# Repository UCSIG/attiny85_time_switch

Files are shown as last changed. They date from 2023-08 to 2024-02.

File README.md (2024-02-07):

# ATtiny85 Time Switch

## Low-power 12/24V time switch with undervoltage protection using the internal oscillator of the ATtiny85

The aim of this project is to switch a load on and off in regular time intervals. The device itself consumes only very little sleep current (~19.6uA on average).  
The device also monitors the supply voltage and turns off the load if the supply drops lower than the defined threshold.

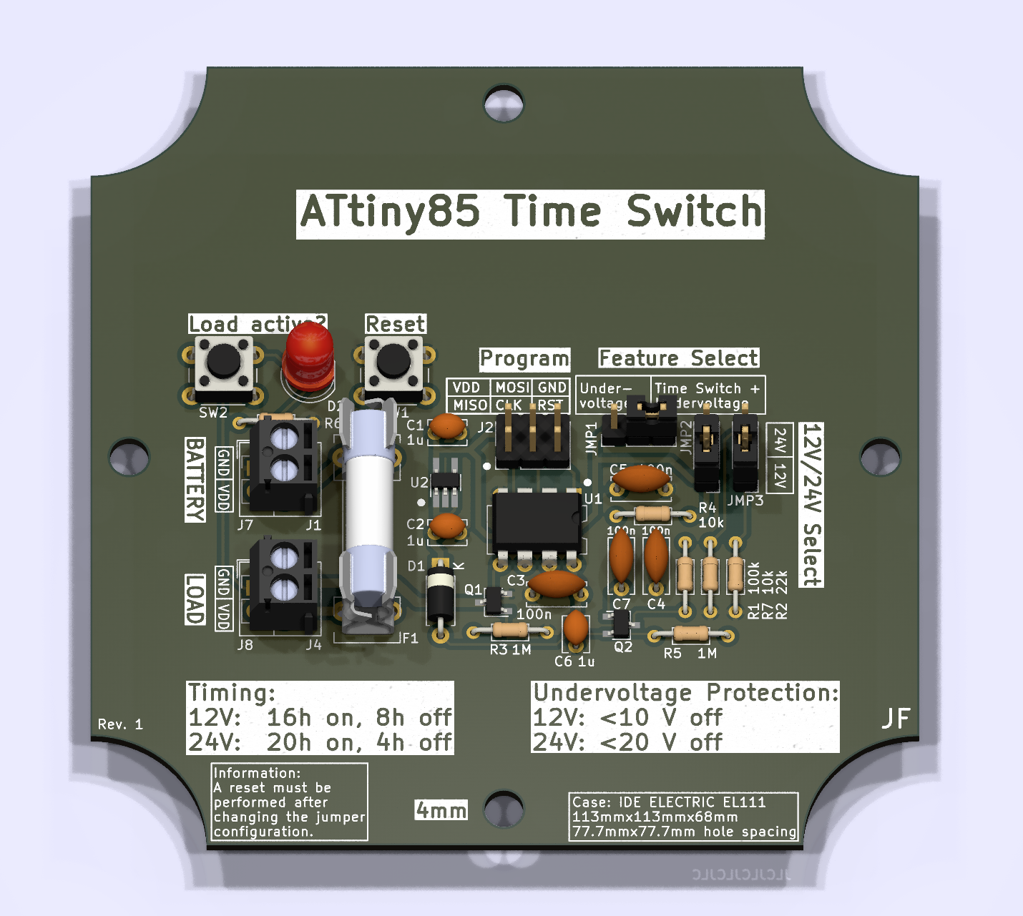
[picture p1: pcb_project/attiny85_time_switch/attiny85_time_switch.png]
PCB 3D View


## Features

- Clock calibration algorithm with values stored in the internal eeprom
- Supply voltage monitoring
- Jumper configuration for feature selection (supply voltage monitoring + time switch/only supply voltage monitoring)
- Jumper configuration for undervoltage threshold selection (12/24V)
- Low current consumption (~19.6uA)

## Specifications

| Type | Value |
| --- | --- |
| Average Current Consumption | 19.6uA |
| Maximum Load Current | 5.7A (cont.) |
| Supply Voltages | 12/24V |
| Switch Type | Low-Side |

## Detailed Description

There are three jumpers which must be set to either select the 12V or the 24V configuration. This changes the on/off times as well as the undervoltage thresholds.  
Every time the jumper configuration is changed, a reset must be performed for the changes to take effect.  

Upon coming out of reset, the device reads its clock calibration values stored in the internal eeprom to provide accurate timings for the time switch.

The device wakes up periodically and immediately goes back to sleep. That way, very long deep sleep periods can be reached.  
The ATtiny85 runs off of the internal 128kHz low speed oscillator during deep sleep. The watchdog timer wakes up the device every 8.192s (the maximum watchdog timeout) and the ATtiny increments a counter variable.
If it surpasses a pre-defined threshold, the load switch changes state from on->off or the other way round.  

Every 15 minutes it also measures the supply voltage and compares it to a pre-defined threshold. If the supply is lower than that threshold, the load is switched off until the device is reset.  
The maximum load current is determined by the sizing of the n-fet Q1. With the n-fet PMV20XNER one can switch up to 5/7A. The load is switched with a low side switch.  

The internal 8MHz oscillator of the ATtiny85 is used as the primary clock source. However, the clock frequency can vary by up to ±15%. In order to get accurate on/off times from the time switch,
this internal oscillator must be calibrated. A detailed description of how to do that can be found [here](clock_calibrations/clock_calibrations.md).

## Mechanical

The pcb is designed to fit in the [EL111](https://ide.es/eng/products/junction-boxes-and-mechanisms/ip65-ip67-junction-boxes/ref_EL111) enclosure by IDE electric.
It is screwed into the case using four M4 screws. The case itself is rated IP65-67. Its dimensions are 113x113x68 mm (Height x Width x Depth).

## Project structure

The code resides in the folder `src` and `include`. PlatformIO is chosen as the build environment. The best way to program the ATtiny85 is to use PlatformIO and VS Code as the IDE.  
The pcb project can be found under `pcb_project/attiny85_time_switch`. The relevant code snippets for changing the timing values and the undervoltage thresholds are at the top of `main.cpp`.
The gerber files are in `pcb_project/attiny85_time_switch/fabrication_outputs/`.

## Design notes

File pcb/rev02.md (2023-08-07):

# ATtiny85 Time Switch Future Revisions

## Rev02

- Use bigger screw terminals (currently 3.5mm hole distance, thats too small, use something like 5mm)

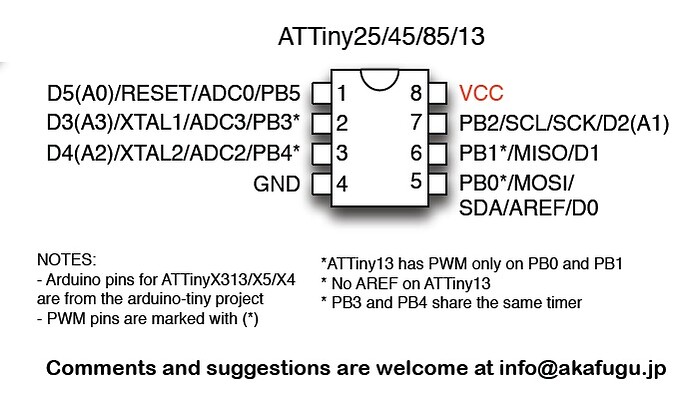
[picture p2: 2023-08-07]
docu/ATtiny85_pinout.jpeg

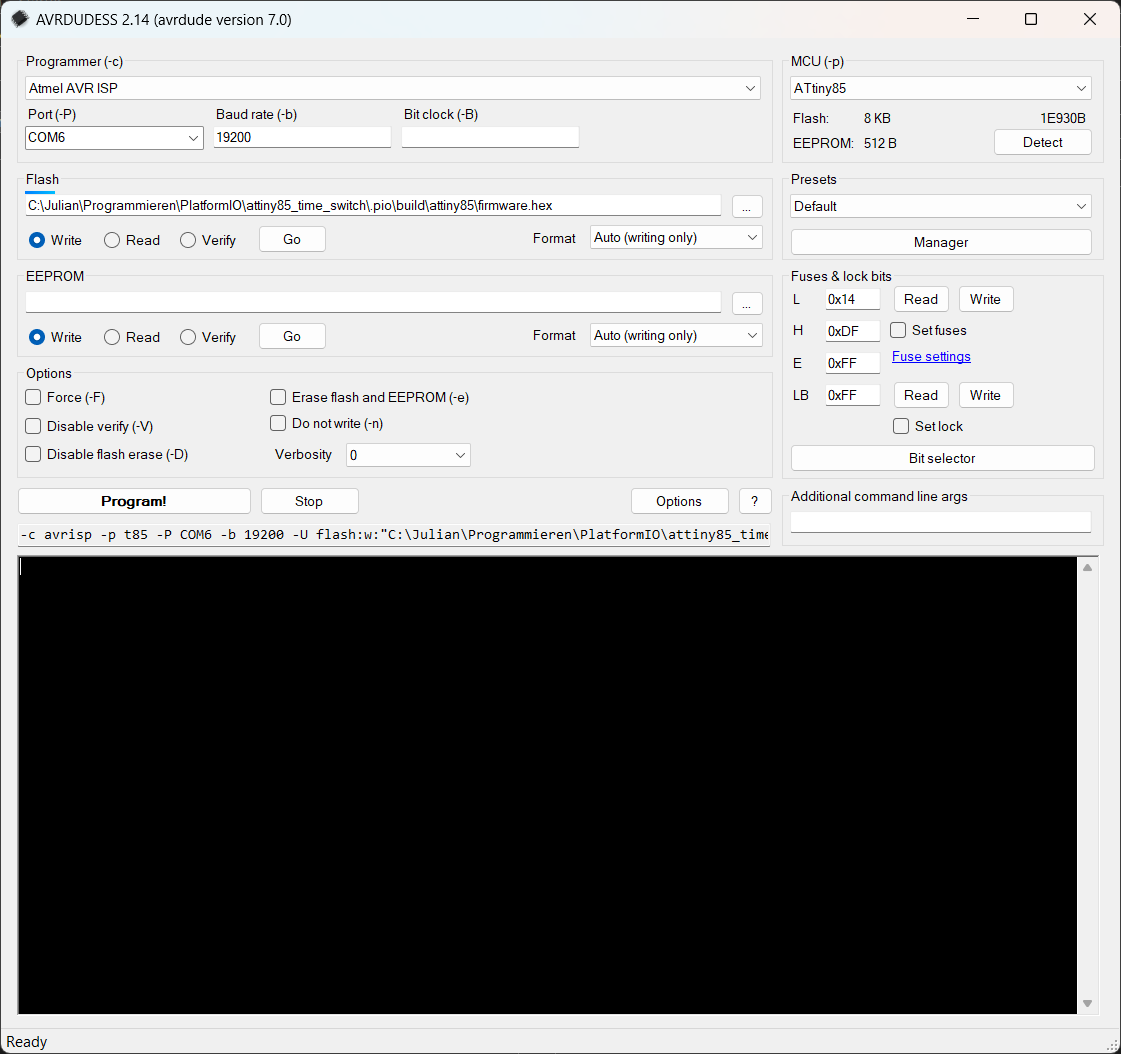
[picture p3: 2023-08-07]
docu/avr_dudess_settings.png

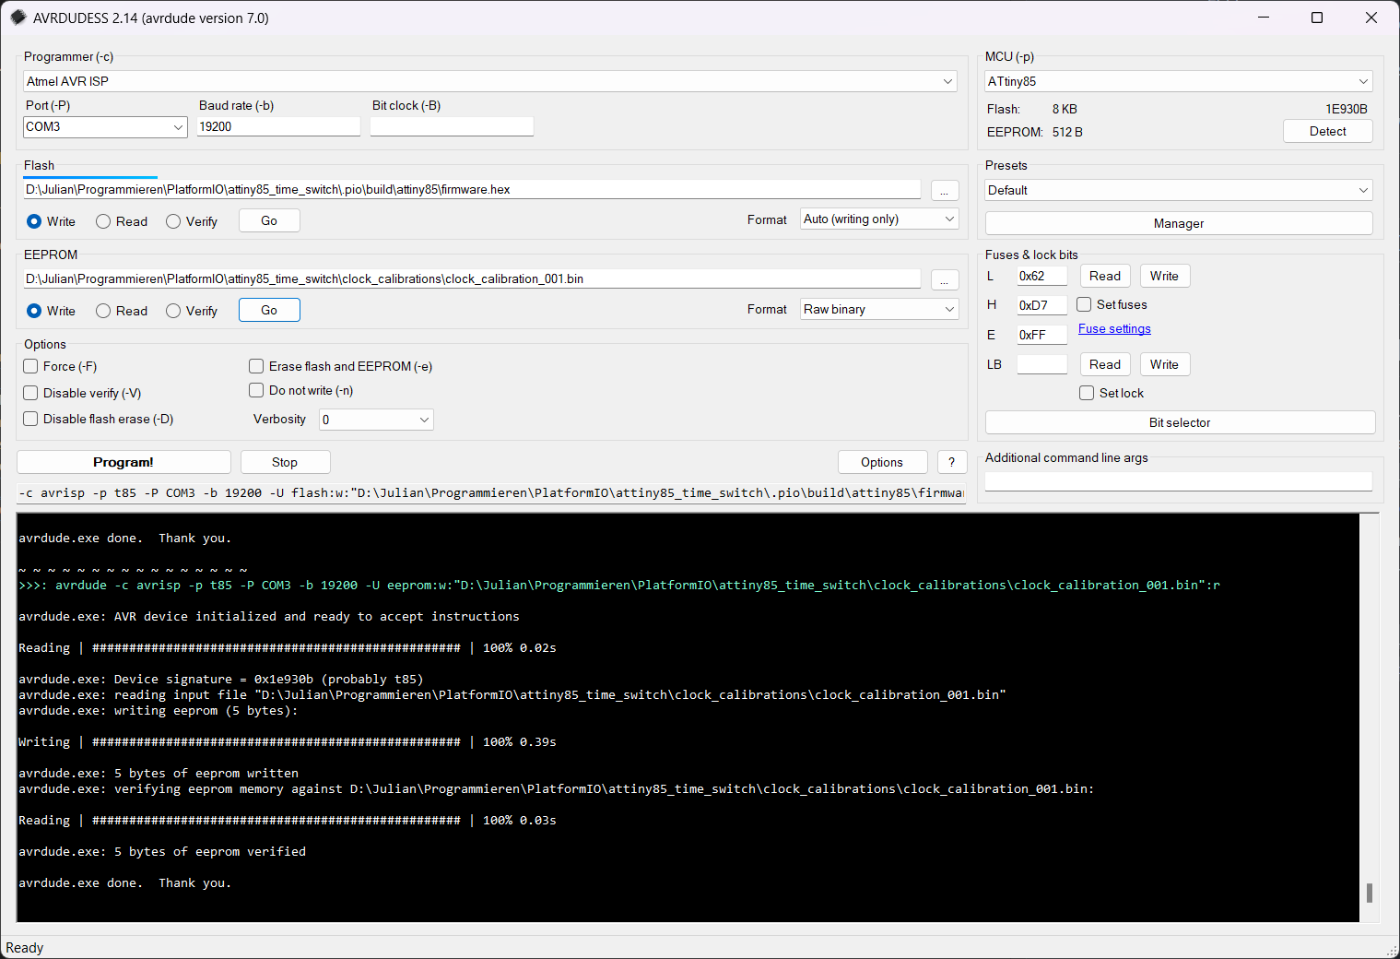
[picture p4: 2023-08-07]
docu/avr_dudess_eeprom_settings.png

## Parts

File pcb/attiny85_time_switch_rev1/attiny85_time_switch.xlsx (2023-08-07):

Reference | Value | Link | Manufacturer Part Number | Menge | So viel haben wir schon
C1, C2, C6 | 1u | https://de.farnell.com/tdk/fg18x5r1h105krt06/kondensator-1uf-50v-mlcc-radial/dp/3619045 | FG18X5R1H105KRT06 | 3 | 38
C3-C5, C7 | 100n | https://de.farnell.com/suntan/ts170r1h104msbfb0r/kondensator-0-1-f-50v-20-y5v/dp/2901306?ost=2901306 | TS170R1H104MSBFB0R | 4 | 35
Case1 | EL111 | https://ide.es/deu/produkte/abzweigdosen-und-schalterdosen/ip65-ip67-ap-abzweigdosen-und-motorschutzgehause/ref_EL111 | EL111 | 1 | Hast du schon glaub ich
D1 | D | https://de.farnell.com/on-semiconductor/1n4007rlg/diode-std-erholzeit-1a-1kv-axial/dp/2317678?st=1n4007 | 1N4007RLG | 1 | Musst du schauen, ob du neue Verpolschutzdioden willst oder einfach irgendeine nimmst die rumliegt
D2 | LED | https://de.farnell.com/multicomp/703-0100/led-rot-5mm-standard/dp/2112111?st=led%205mm | 703-0100 | 1 | Halt eine LED :D
F1 | 0751.0052 | https://de.farnell.com/schurter/0751-0052/fuse-clip-pcb-mount/dp/2309093?ost=0751.0052 | 0751.0052 | 1 | Du meintest, du hast schon die Halterung und die Sicherung
J1, J4 | Screw_Terminal_01x02 | https://de.farnell.com/camdenboss/ctb0305-2/anschlussblock-2polig/dp/3882639?st=ctb0305 | CTB0305/2 | 2 | Je nachdem, wie du die Kabel befestigen willst, das wäre eine passende Schraubklemme mit 3.5mm Lochabstand
J2 | Conn_02x03_Pin | https://de.farnell.com/multicomp/2213s-06g/stecker-2-reih-vert-6kont/dp/1593440 | 2213S-06G | 1 | Vielleicht macht es Sinn, hier passende zweireihige Stiftleisten zu bestellen. Das ist für den Programmieranschluss, man könnte auch zwei einreihige Stiftleisten auf je 3 Kontakte schneiden und nebeneinander einlöten, aber ist doch cooler wenn das direkt gut passt alles
J3, J5, J6 | Conn_01x03_Pin | https://de.farnell.com/multicomp/spc20484/stecker-1reihen-40kont/dp/1462888 | SPC20484 | 3 | Standard 2.54mm Stiftleisten, die für die Jumperkonfiguration gebraucht wird. Wir brauchen pro Platine 9 Kontakte für die Jumperkonfiguration, und 4 Kontakte falls du da die Kabel für Batterie und Last anschließen willst (anstelle von anlöten oder Schraubklemmen)
J7, J8 | Conn_01x02_Pin | https://de.farnell.com/multicomp/spc20484/stecker-1reihen-40kont/dp/1462888 | SPC20484 | 2 | wie oben
Q1 | PMV20XNER | https://de.farnell.com/nexperia/pmv20xner/mosfet-n-kanal-30v-5-7a-to236ab/dp/2498579?ost=2498579 | PMV20XNER | 1 | 0
Q2 | PMV65XP,215 | https://de.farnell.com/infineon/irlml6402trpbf/mosfet-p-kanal-20v-3-7a-sot-23/dp/9103503?st=p%20fet | IRLML6402TRPBF | 1 | 0
R1, R5 | 100k |  |  | 2 | Widerstand halt
R2, R4 | 10k |  |  | 2 | Widerstand halt
R3 | 1M |  |  | 1 | Widerstand halt
R6 | 3k3 |  |  | 1 | Widerstand halt
R7 | 22k |  |  | 1 | Widerstand halt
SW1 | Reset | https://de.farnell.com/e-switch/tl1105af160q/taster-0-05a-12v-dc-160gf-tht/dp/4051069?MER=sy-me-pd-mi-alte | TL1105AF160Q | 1 | Standard Taster mit 4.5mm und 6.5mm Lochabstand. Für Reset Button und um zu schauen ob die Last an ist, denke das ist praktisch fürs schnelle Testing.
SW2 | Check FET | https://de.farnell.com/e-switch/tl1105af160q/taster-0-05a-12v-dc-160gf-tht/dp/4051069?MER=sy-me-pd-mi-alte | TL1105AF160Q | 1 | wie oben
U1 | ATtiny85V-10P | https://de.farnell.com/microchip/attiny85v-10pu/avr-mcu-8k-flash-512b-ram-dip8/dp/1455165?ost=1455165 | ATTINY85V-10PU | 1 | 19
U2 | AP7383-50W5-7 | https://de.farnell.com/diodes-inc/ap7383-50w5-7/ldo-festsp-regl-5v-0-15a-40-bis/dp/3518352?ost=3518352 | AP7383-50W5-7 | 1 | 0

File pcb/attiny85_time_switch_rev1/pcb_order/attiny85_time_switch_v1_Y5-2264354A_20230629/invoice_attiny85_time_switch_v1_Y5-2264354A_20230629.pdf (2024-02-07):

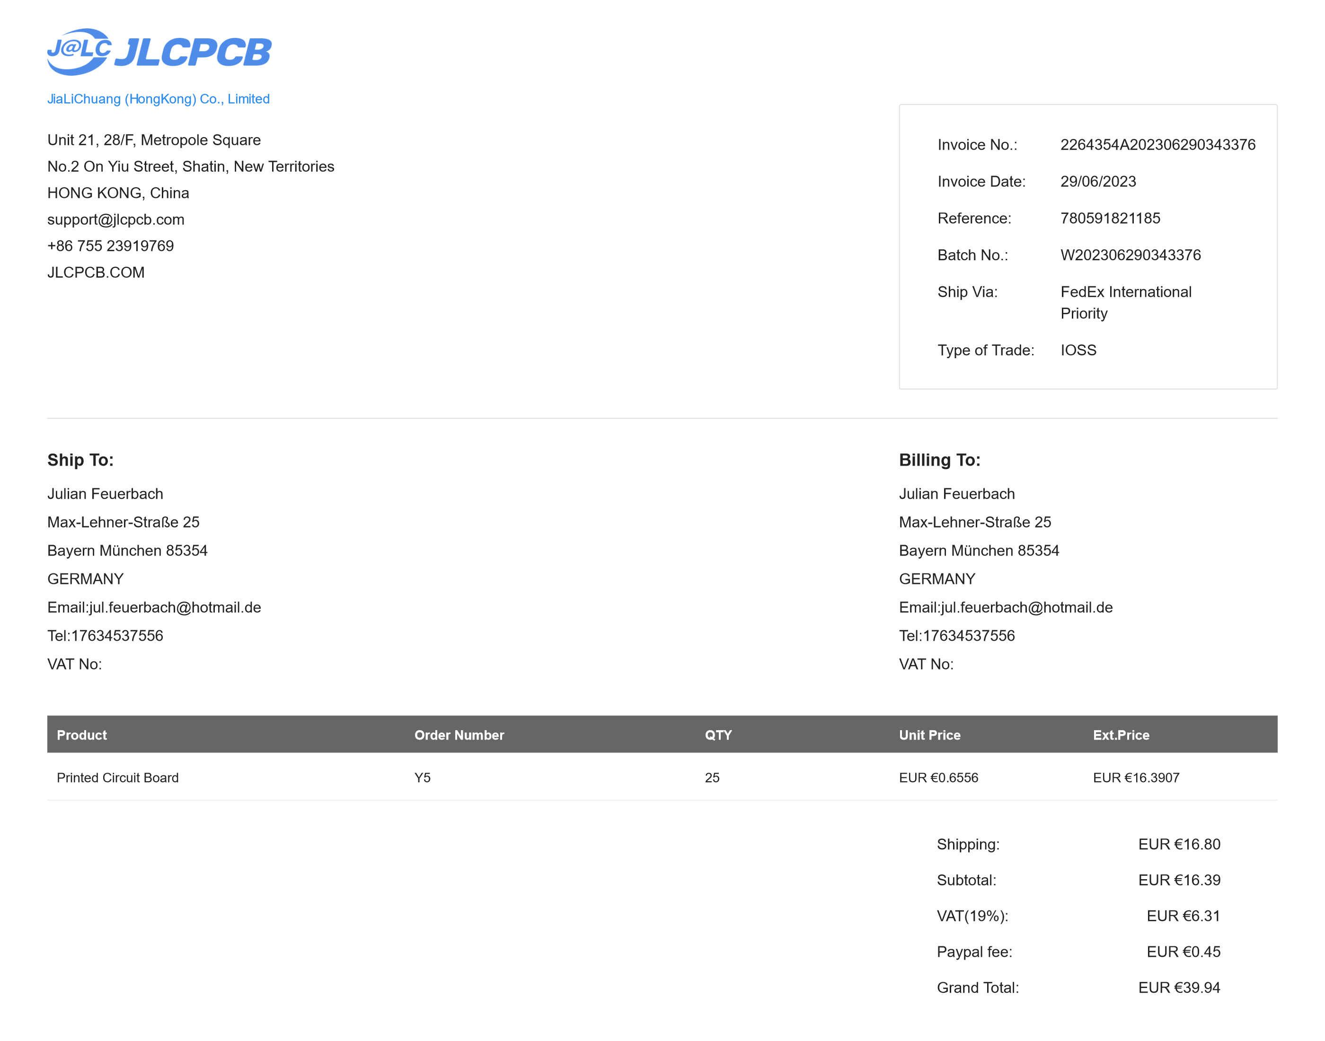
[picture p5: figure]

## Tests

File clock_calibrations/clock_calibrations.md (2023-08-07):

# Clock Calibration Values

The internal 128kHz rc oscillator is very unprecise (up to +-15%) and therefore requires some calibration.
By calculating the frequency compensation values and writing them to the internal eeprom, the error can be reduced.  
This document describes how this is done.

## Calibration procedure

- Remove feature select jumper JMP1
- Hook up an oscilloscope probe on pin 2 (middle pin) of feature select jumper JMP1 (PB4 of attiny), ground is on pin 3, right of middle pin
- Program the attiny with the `CLOCK_CALIBRATION_MODE` defined
- Program the fuse bits `L: 0x94`, `H: 0xD7`, `E: 0xFF`
- Measure the frequency on pin 2 of JMP1
- Write the chip id (just increasing numbers) on a sticky note and stick it to the attiny
- Write the chip id in the table [below](#actual-calibration-values)
- Write the frequency in the table [below](#actual-calibration-values)
- Run the script [generate_bin_data.py](generate_bin_data.py) in this folder
- Write the produced [clock_calibration_xxx.bin](clock_calibration_001.bin) file with avrdudess to the eeprom (settings in [avr_dudess_eeprom_settings.png](../docu/avr_dudess_eeprom_settings.png)) (check for output of avr dudess!)

## Actual calibration Values

The files to be programmed with avrdudess into the eeprom can be generated with the script `generate_bin_data.py`.

| Chip ID | Frequency (Hz) | Clock Calibration Value in eeprom (hex value of frequency column) |
| --- | --- | --- |
| 1 | 110481 | 0x0001af91 |
| 2 | 111976 | 0x0001b568 |
| 3 | 114584 | 0x0001bf98 |
| 4 | 108488 | 0x0001a7c8 |
| 5 | 111978 | 0x0001b56a |
| 6 | 113371 | 0x0001badb |
| 7 | 113827 | 0x0001bca3 |
| 8 | 109239 | 0x0001aab7 |
| 9 | 112813 | 0x0001b8ad |
| 10 | 109103 | 0x0001aa2f |
| 11 | 110534 | 0x0001afc6 |
| 12 | 116008 | 0x0001c528 |
| 13 | 111055 | 0x0001b1cf |
| 14 | 115564 | 0x0001c36c |
| 16 | 107913 | 0x0001a589 |

## Fuse settings

- L: 94
  - 128kHz. CKOUT: Clock out on PB4 feature select (no jumper!). Requires slow SCK programming clock.
- H: D7
  - EESAVE: EEPROM memory is preserved through the chip erase. SPIEN: enable serial program and data downloading.
- E: FF
  - Self-programming disabled.

128kHz main clock requires slow SCK programming clock (maximum 26kHz).

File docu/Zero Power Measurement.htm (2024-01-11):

The Wayback Machine - https://web.archive.org/web/20221230225158/https://jeelabs.org/2013/05/18/zero-power-measurement-part-2/

# Computing stuff tied to the physical world (https://web.archive.org/web/20221230225158/https://jeelabs.org/index.html)

# JeeLabs (https://web.archive.org/web/20221230225158/https://jeelabs.org/index.html)

- Intro (https://web.archive.org/web/20221230225158/https://jeelabs.org/intro/index.html)|
- Docs (https://web.archive.org/web/20221230225158/https://jeelabs.org/cafe/index.html)|
- Forum (https://web.archive.org/web/20221230225158/https://jeelabs.org/talk/index.html)|
- Book (https://web.archive.org/web/20221230225158/https://jeelabs.org/book/index.html)|
- Shop (https://web.archive.org/web/20221230225158/https://jeelabs.org/shop/index.html)|
- About (https://web.archive.org/web/20221230225158/https://jeelabs.org/about/index.html)|
- Archives (https://web.archive.org/web/20221230225158/https://jeelabs.org/2015/index.html)|
- RSS Feed (https://web.archive.org/web/20221230225158/https://jeelabs.org/feed/index.html)

LowPower (https://web.archive.org/web/20221230225158/https://jeelabs.org/tag/lowpower/index.html), Electronics (https://web.archive.org/web/20221230225158/https://jeelabs.org/tag/electronics/index.html)

## Zero-power measurement – part 2

In Hardware (https://web.archive.org/web/20221230225158/https://jeelabs.org/category/hardware/index.html) on May 18, 2013 at 00:01

After a great suggestion (https://web.archive.org/web/20221230225158/https://jeelabs.org/2013/05/17/zero-powe-battery-measurement/index.html) by Max, on yesterday’s post, here’s a another circuit to try:

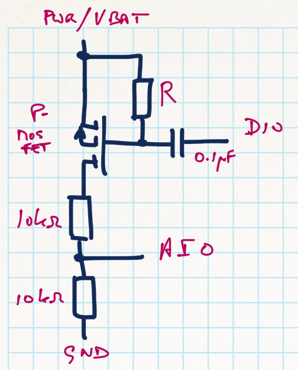
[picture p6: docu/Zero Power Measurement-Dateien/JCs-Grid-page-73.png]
JC's Grid, page 73
 (https://web.archive.org/web/20221230225158/https://jeelabs.org/wp-content/uploads/2013/05/JCs-Grid-page-73.png)

It adds a capacitor and a resistor, but it allows using a P-MOSFET and a divider ratio which can now use the entire ADC range, not just 1 V or so as in yesterday’s circuit. Note however that if VCC is not fixed to the same value under all conditions, then the ADC’s reference voltage can float, and use of the 1.1V bandgap may still be needed.

Here’s the voltage at the top of the divider, showing how it switches on and off:

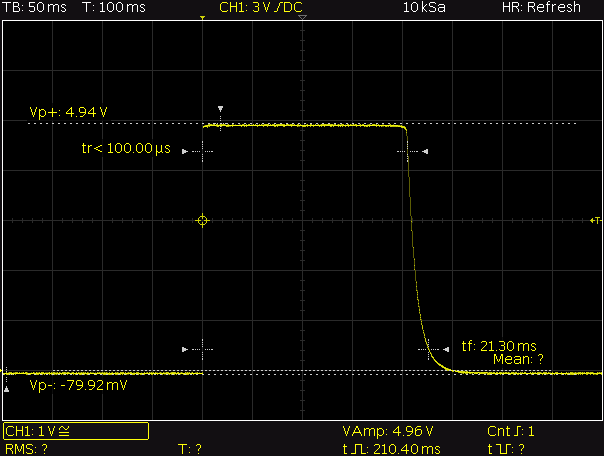
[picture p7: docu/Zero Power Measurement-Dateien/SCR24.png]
SCR24
 (https://web.archive.org/web/20221230225158/https://jeelabs.org/wp-content/uploads/2013/05/SCR24.png)

That’s with the pull-up resistor value R set to 1 MΩ, which takes 208 ms to turn the MOSFET back off. We don’t need that long, a 10 kΩ resistor for R will do fine:

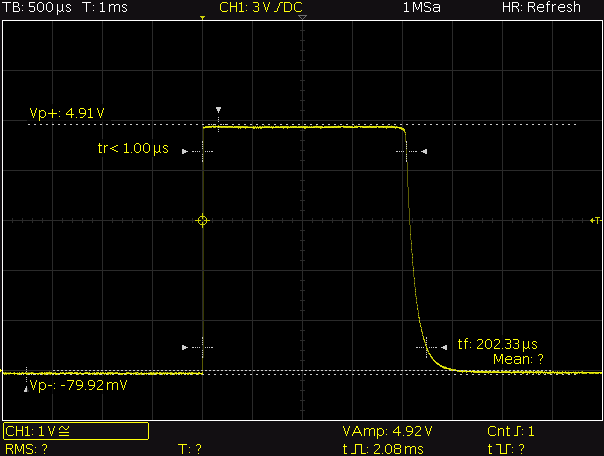
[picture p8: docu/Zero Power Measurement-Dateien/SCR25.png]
SCR25
 (https://web.archive.org/web/20221230225158/https://jeelabs.org/wp-content/uploads/2013/05/SCR25.png)

That still gives us 2 ms to measure the supply level. Note that turn-off is automatic. DIO needs to be turned high again, but that can happen later. In my test code, I left it low for 1s to, then high for 7s.

Here’s a neat set of superimposed measurements (using persistence), while varying the high voltage from 3.5 to 12.0 V in 0.5 V steps:

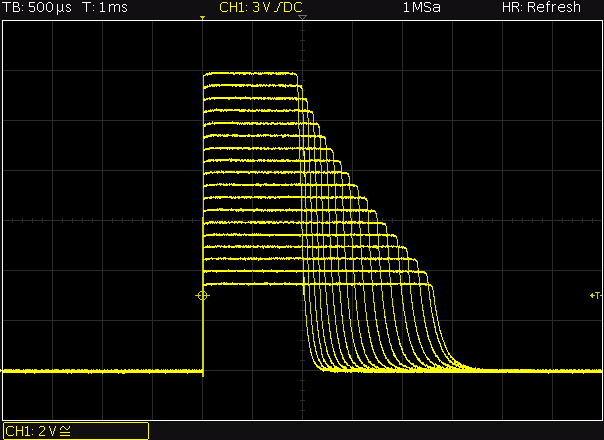
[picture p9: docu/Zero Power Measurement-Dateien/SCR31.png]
SCR31
 (https://web.archive.org/web/20221230225158/https://jeelabs.org/wp-content/uploads/2013/05/SCR31.png)

Warning: for 12V, the divider ratio must be changed so the centre tap stays under VCC.

Note that with higher voltages, the MOSFET will turn off sooner – this is because there is now more current flowing through the pull-up resistor. But still plenty of time left to measure: 1 ms is more than enough for an ADC.

Tomorrow, an example of how these measurements can sometimes go awry…

▶ View 2 Comments

1. This is a great solution, but I find it hard to source small-signal MOSFETs locally. Can anyone recommend a suitable P-MOSFET type for this application? Preferably thru-hole i.e. T092 package or similar. SMD is hard to handle on 0.1″ grid proto boards.
  damonb 18 May 2013 at 7am
  - Probably just about any type P-MOSFET will work here, I expect. Keep an eye on the Vgs parameter, lower is better. Perhaps search for “p-mosfet to92” on Farnell?
    jcw 18 May 2013 at 11am

Comments are closed.

« Before Zero-power battery measurement May 17, 2013 (https://web.archive.org/web/20221230225158/https://jeelabs.org/2013/05/17/zero-powe-battery-measurement/index.html)

AfterSupply noise sensitivity May 19, 2013 » (https://web.archive.org/web/20221230225158/https://jeelabs.org/2013/05/19/supply-noise-sensitivity/index.html)

### Recent Posts

    - Turning the page on 2015 (https://web.archive.org/web/20221230225158/https://jeelabs.org/2015/12/29/turning-the-page-on-2015/index.html)
    - Tying up 2015’s loose ends (https://web.archive.org/web/20221230225158/https://jeelabs.org/2015/12/23/tying-up-2015s-loose-ends/index.html)
    - Switching to a new server (https://web.archive.org/web/20221230225158/https://jeelabs.org/2015/12/16/switching-to-a-new-server/index.html)
    - A diversion into FPGAs (https://web.archive.org/web/20221230225158/https://jeelabs.org/2015/12/09/a-diversion-into-fpgas/index.html)
    - A fingernail vs a moon lander (https://web.archive.org/web/20221230225158/https://jeelabs.org/2015/12/02/a-fingernail-vs-a-moon-lander/index.html)
    - Pi-based STM32F103 development (https://web.archive.org/web/20221230225158/https://jeelabs.org/2015/11/25/pi-based-stm32f103-development/index.html)
    - Programmer PCB Triple Play (https://web.archive.org/web/20221230225158/https://jeelabs.org/2015/11/18/programmer-pcb-triple-play/index.html)
    - Talking to an STM32 (https://web.archive.org/web/20221230225158/https://jeelabs.org/2015/11/11/talking-to-an-stm32/index.html)
    - The world of STM32 (https://web.archive.org/web/20221230225158/https://jeelabs.org/2015/11/04/the-world-of-stm32/index.html)
    - Making a sharp turn (https://web.archive.org/web/20221230225158/https://jeelabs.org/2015/10/28/making-a-sharp-turn/index.html)
    - IDE w/ LPC824, part 2 (https://web.archive.org/web/20221230225158/https://jeelabs.org/2015/10/21/ide-w-lpc824-part-2/index.html)
    - Arduino IDE w/ LPC824 (https://web.archive.org/web/20221230225158/https://jeelabs.org/2015/10/14/arduino-ide-w-lpc824/index.html)
    - Meet the Tinker Pico (again) (https://web.archive.org/web/20221230225158/https://jeelabs.org/2015/10/07/meet-the-tinker-pico-again/index.html)
    - Getting back in the groove (https://web.archive.org/web/20221230225158/https://jeelabs.org/2015/09/30/getting-back-in-the-groove/index.html)
    - Shedding weight (https://web.archive.org/web/20221230225158/https://jeelabs.org/2015/09/23/shedding-weight/index.html)
    - Bandwagons and islands (https://web.archive.org/web/20221230225158/https://jeelabs.org/2015/09/16/bandwagons-and-islands/index.html)
    - Hundertwasser (https://web.archive.org/web/20221230225158/https://jeelabs.org/2015/09/09/hundertwasser/index.html)
    - Space tools (https://web.archive.org/web/20221230225158/https://jeelabs.org/2015/09/02/space-tools/index.html)
    - Clojure and ClojureScript (https://web.archive.org/web/20221230225158/https://jeelabs.org/2015/08/26/clojure-and-clojurescript/index.html)
    - A feel for numbers (https://web.archive.org/web/20221230225158/https://jeelabs.org/2015/08/19/a-feel-for-numbers/index.html)
    - Lessons from history (https://web.archive.org/web/20221230225158/https://jeelabs.org/2015/08/12/lessons-from-history/index.html)
    - Doodling with decoders (https://web.archive.org/web/20221230225158/https://jeelabs.org/2015/08/05/doodling-with-decoders/index.html)
    - Could a coin cell be enough? (https://web.archive.org/web/20221230225158/https://jeelabs.org/2015/07/29/could-a-coin-cell-be-enough/index.html)
    - Forth on a DIP (https://web.archive.org/web/20221230225158/https://jeelabs.org/2015/07/22/forth-on-a-dip/index.html)
    - RFM69s, OOK, and antennas (https://web.archive.org/web/20221230225158/https://jeelabs.org/2015/07/15/rfm69s-ook-and-antennas/index.html)
    - Greasing the “make” cycle on Mac (https://web.archive.org/web/20221230225158/https://jeelabs.org/2015/07/08/greasing-the-make-cycle-on-mac/index.html)
    - Low-power mode :) (https://web.archive.org/web/20221230225158/https://jeelabs.org/2015/07/01/low-power-mode/index.html)
    - FTDI over WiFi: esp-bridge (https://web.archive.org/web/20221230225158/https://jeelabs.org/2015/06/24/ftdi-over-wifi-esp-bridge/index.html)
    - Moving up a (few) level(s) (https://web.archive.org/web/20221230225158/https://jeelabs.org/2015/06/17/moving-up-a-few-levels/index.html)
    - Code for the LPC8xx (https://web.archive.org/web/20221230225158/https://jeelabs.org/2015/06/10/code-for-the-lpc824/index.html)
    - Introducing the LPC824 (https://web.archive.org/web/20221230225158/https://jeelabs.org/2015/06/03/introducing-the-lpc824/index.html)
    - RFM69 on ATmega (https://web.archive.org/web/20221230225158/https://jeelabs.org/2015/05/27/rfm69-on-atmega/index.html)
    - RFM69 on Raspberry Pi (https://web.archive.org/web/20221230225158/https://jeelabs.org/2015/05/20/rfm69-on-raspberry-pi/index.html)
    - Micro Power Snitch, success! (https://web.archive.org/web/20221230225158/https://jeelabs.org/2015/05/13/micro-power-snitch-success/index.html)
    - Micro Power Snitch, part 7 (https://web.archive.org/web/20221230225158/https://jeelabs.org/2015/05/06/micro-power-snitch-part-7/index.html)
    - Micro Power Snitch, part 6 (https://web.archive.org/web/20221230225158/https://jeelabs.org/2015/04/29/micro-power-snitch-part-6/index.html)
    - We interrupt this program (https://web.archive.org/web/20221230225158/https://jeelabs.org/2015/04/22/we-interrupt-this-program/index.html)
    - Dataflash via SPI (https://web.archive.org/web/20221230225158/https://jeelabs.org/2015/04/15/dataflash-via-spi-2/index.html)
    - Analog on the cheap (https://web.archive.org/web/20221230225158/https://jeelabs.org/2015/04/08/analog-on-the-cheap/index.html)
    - Emulating EEPROM (https://web.archive.org/web/20221230225158/https://jeelabs.org/2015/04/01/emulating-eeprom/index.html)
    - From LPC810 to LPC812 (https://web.archive.org/web/20221230225158/https://jeelabs.org/2015/03/25/from-lpc810-to-lpc812/index.html)
    - Micro Power Snitch, last part (https://web.archive.org/web/20221230225158/https://jeelabs.org/2015/03/18/micro-power-snitch-last-part/index.html)
    - Micro Power Snitch, part 4 (https://web.archive.org/web/20221230225158/https://jeelabs.org/2015/03/11/micro-power-snitch-part-4/index.html)
    - Micro Power Snitch, part 3 (https://web.archive.org/web/20221230225158/https://jeelabs.org/2015/03/04/micro-power-snitch-part-3/index.html)
    - Micro Power Snitch, part 2 (https://web.archive.org/web/20221230225158/https://jeelabs.org/2015/02/25/micro-power-snitch-part-2/index.html)
    - Micro Power Snitch (https://web.archive.org/web/20221230225158/https://jeelabs.org/2015/02/18/micro-power-snitch/index.html)
    - Uploading over serial (https://web.archive.org/web/20221230225158/https://jeelabs.org/2015/02/11/uploading-over-serial/index.html)
    - Bits, pointers, and interrupts (https://web.archive.org/web/20221230225158/https://jeelabs.org/2015/02/04/bits-pointers-and-interrupts/index.html)
    - LPC810 meets RFM69, part 3 (https://web.archive.org/web/20221230225158/https://jeelabs.org/2015/01/28/lpc810-meets-rfm69-part-3/index.html)
    - Volta makes the world go round (https://web.archive.org/web/20221230225158/https://jeelabs.org/2015/01/21/volta-makes-the-world-go-round/index.html)
    - Embedded Linux (https://web.archive.org/web/20221230225158/https://jeelabs.org/2015/01/14/embedded-linux/index.html)
    - LPC810 meets RFM69, part 2 (https://web.archive.org/web/20221230225158/https://jeelabs.org/2015/01/07/lpc810-meets-rfm69-part-2/index.html)
    - LPC810 meets RFM69 (https://web.archive.org/web/20221230225158/https://jeelabs.org/2014/12/31/lpc810-meets-rfm69/index.html)
    - Eye Squared See (https://web.archive.org/web/20221230225158/https://jeelabs.org/2014/12/24/eye-squared-see/index.html)
    - Schematics and layouts (https://web.archive.org/web/20221230225158/https://jeelabs.org/2014/12/17/schematics-and-layouts/index.html)
    - Dip into the LPC810 (https://web.archive.org/web/20221230225158/https://jeelabs.org/2014/12/10/dip-into-the-lpc810/index.html)
    - Garage Parking Aid (https://web.archive.org/web/20221230225158/https://jeelabs.org/2014/12/03/garage-parking-aid/index.html)
    - Getting started, final episode (https://web.archive.org/web/20221230225158/https://jeelabs.org/2014/11/26/getting-started-final-episode/index.html)
    - Getting started, episode 3 (https://web.archive.org/web/20221230225158/https://jeelabs.org/2014/11/19/getting-started-episode-3/index.html)
    - Getting started, episode 2 (https://web.archive.org/web/20221230225158/https://jeelabs.org/2014/11/13/getting-started-episode-2/index.html)

## Archives

    - December 2015 (https://web.archive.org/web/20221230225158/https://jeelabs.org/2015/12/index.html)
    - November 2015 (https://web.archive.org/web/20221230225158/https://jeelabs.org/2015/11/index.html)
    - October 2015 (https://web.archive.org/web/20221230225158/https://jeelabs.org/2015/10/index.html)
    - September 2015 (https://web.archive.org/web/20221230225158/https://jeelabs.org/2015/09/index.html)
    - August 2015 (https://web.archive.org/web/20221230225158/https://jeelabs.org/2015/08/index.html)
    - July 2015 (https://web.archive.org/web/20221230225158/https://jeelabs.org/2015/07/index.html)
    - June 2015 (https://web.archive.org/web/20221230225158/https://jeelabs.org/2015/06/index.html)
    - May 2015 (https://web.archive.org/web/20221230225158/https://jeelabs.org/2015/05/index.html)
    - April 2015 (https://web.archive.org/web/20221230225158/https://jeelabs.org/2015/04/index.html)
    - March 2015 (https://web.archive.org/web/20221230225158/https://jeelabs.org/2015/03/index.html)
    - February 2015 (https://web.archive.org/web/20221230225158/https://jeelabs.org/2015/02/index.html)
    - January 2015 (https://web.archive.org/web/20221230225158/https://jeelabs.org/2015/01/index.html)
    - December 2014 (https://web.archive.org/web/20221230225158/https://jeelabs.org/2014/12/index.html)
    - November 2014 (https://web.archive.org/web/20221230225158/https://jeelabs.org/2014/11/index.html)
    - October 2014 (https://web.archive.org/web/20221230225158/https://jeelabs.org/2014/10/index.html)
    - October 2013 (https://web.archive.org/web/20221230225158/https://jeelabs.org/2013/10/index.html)
    - September 2013 (https://web.archive.org/web/20221230225158/https://jeelabs.org/2013/09/index.html)
    - July 2013 (https://web.archive.org/web/20221230225158/https://jeelabs.org/2013/07/index.html)
    - June 2013 (https://web.archive.org/web/20221230225158/https://jeelabs.org/2013/06/index.html)
    - May 2013 (https://web.archive.org/web/20221230225158/https://jeelabs.org/2013/05/index.html)
    - April 2013 (https://web.archive.org/web/20221230225158/https://jeelabs.org/2013/04/index.html)
    - March 2013 (https://web.archive.org/web/20221230225158/https://jeelabs.org/2013/03/index.html)
    - February 2013 (https://web.archive.org/web/20221230225158/https://jeelabs.org/2013/02/index.html)
    - January 2013 (https://web.archive.org/web/20221230225158/https://jeelabs.org/2013/01/index.html)
    - December 2012 (https://web.archive.org/web/20221230225158/https://jeelabs.org/2012/12/index.html)
    - November 2012 (https://web.archive.org/web/20221230225158/https://jeelabs.org/2012/11/index.html)
    - October 2012 (https://web.archive.org/web/20221230225158/https://jeelabs.org/2012/10/index.html)
    - September 2012 (https://web.archive.org/web/20221230225158/https://jeelabs.org/2012/09/index.html)
    - July 2012 (https://web.archive.org/web/20221230225158/https://jeelabs.org/2012/07/index.html)
    - June 2012 (https://web.archive.org/web/20221230225158/https://jeelabs.org/2012/06/index.html)
    - May 2012 (https://web.archive.org/web/20221230225158/https://jeelabs.org/2012/05/index.html)
    - April 2012 (https://web.archive.org/web/20221230225158/https://jeelabs.org/2012/04/index.html)
    - March 2012 (https://web.archive.org/web/20221230225158/https://jeelabs.org/2012/03/index.html)
    - February 2012 (https://web.archive.org/web/20221230225158/https://jeelabs.org/2012/02/index.html)
    - January 2012 (https://web.archive.org/web/20221230225158/https://jeelabs.org/2012/01/index.html)
    - December 2011 (https://web.archive.org/web/20221230225158/https://jeelabs.org/2011/12/index.html)
    - November 2011 (https://web.archive.org/web/20221230225158/https://jeelabs.org/2011/11/index.html)
    - October 2011 (https://web.archive.org/web/20221230225158/https://jeelabs.org/2011/10/index.html)
    - September 2011 (https://web.archive.org/web/20221230225158/https://jeelabs.org/2011/09/index.html)
    - June 2011 (https://web.archive.org/web/20221230225158/https://jeelabs.org/2011/06/index.html)
    - May 2011 (https://web.archive.org/web/20221230225158/https://jeelabs.org/2011/05/index.html)
    - March 2011 (https://web.archive.org/web/20221230225158/https://jeelabs.org/2011/03/index.html)
    - February 2011 (https://web.archive.org/web/20221230225158/https://jeelabs.org/2011/02/index.html)
    - January 2011 (https://web.archive.org/web/20221230225158/https://jeelabs.org/2011/01/index.html)
    - December 2010 (https://web.archive.org/web/20221230225158/https://jeelabs.org/2010/12/index.html)
    - November 2010 (https://web.archive.org/web/20221230225158/https://jeelabs.org/2010/11/index.html)
    - October 2010 (https://web.archive.org/web/20221230225158/https://jeelabs.org/2010/10/index.html)
    - September 2010 (https://web.archive.org/web/20221230225158/https://jeelabs.org/2010/09/index.html)
    - August 2010 (https://web.archive.org/web/20221230225158/https://jeelabs.org/2010/08/index.html)
    - July 2010 (https://web.archive.org/web/20221230225158/https://jeelabs.org/2010/07/index.html)
    - June 2010 (https://web.archive.org/web/20221230225158/https://jeelabs.org/2010/06/index.html)
    - May 2010 (https://web.archive.org/web/20221230225158/https://jeelabs.org/2010/05/index.html)
    - April 2010 (https://web.archive.org/web/20221230225158/https://jeelabs.org/2010/04/index.html)
    - March 2010 (https://web.archive.org/web/20221230225158/https://jeelabs.org/2010/03/index.html)
    - February 2010 (https://web.archive.org/web/20221230225158/https://jeelabs.org/2010/02/index.html)
    - January 2010 (https://web.archive.org/web/20221230225158/https://jeelabs.org/2010/01/index.html)
    - December 2009 (https://web.archive.org/web/20221230225158/https://jeelabs.org/2009/12/index.html)
    - November 2009 (https://web.archive.org/web/20221230225158/https://jeelabs.org/2009/11/index.html)
    - October 2009 (https://web.archive.org/web/20221230225158/https://jeelabs.org/2009/10/index.html)
    - September 2009 (https://web.archive.org/web/20221230225158/https://jeelabs.org/2009/09/index.html)
    - August 2009 (https://web.archive.org/web/20221230225158/https://jeelabs.org/2009/08/index.html)
    - July 2009 (https://web.archive.org/web/20221230225158/https://jeelabs.org/2009/07/index.html)
    - June 2009 (https://web.archive.org/web/20221230225158/https://jeelabs.org/2009/06/index.html)
    - May 2009 (https://web.archive.org/web/20221230225158/https://jeelabs.org/2009/05/index.html)
    - April 2009 (https://web.archive.org/web/20221230225158/https://jeelabs.org/2009/04/index.html)
    - March 2009 (https://web.archive.org/web/20221230225158/https://jeelabs.org/2009/03/index.html)
    - February 2009 (https://web.archive.org/web/20221230225158/https://jeelabs.org/2009/02/index.html)
    - January 2009 (https://web.archive.org/web/20221230225158/https://jeelabs.org/2009/01/index.html)
    - December 2008 (https://web.archive.org/web/20221230225158/https://jeelabs.org/2008/12/index.html)
    - November 2008 (https://web.archive.org/web/20221230225158/https://jeelabs.org/2008/11/index.html)
    - October 2008 (https://web.archive.org/web/20221230225158/https://jeelabs.org/2008/10/index.html)
    - ARM (https://web.archive.org/web/20221230225158/https://jeelabs.org/category/arm/index.html)
    - AVR (https://web.archive.org/web/20221230225158/https://jeelabs.org/category/avr/index.html)
    - Book (https://web.archive.org/web/20221230225158/https://jeelabs.org/category/book/index.html)
    - Hardware (https://web.archive.org/web/20221230225158/https://jeelabs.org/category/hardware/index.html)
    - Linux (https://web.archive.org/web/20221230225158/https://jeelabs.org/category/linux/index.html)
    - Musings (https://web.archive.org/web/20221230225158/https://jeelabs.org/category/musings/index.html)
    - News (https://web.archive.org/web/20221230225158/https://jeelabs.org/category/news/index.html)

### About

  - "Jee" stands for JC's Environmental Electronics. This blog is maintained by Jean-Claude Wippler.
  - Search for:
  - Alphabetical (https://web.archive.org/web/20221230225158/https://jeelabs.org/pub/index-a.html) and Chronological (https://web.archive.org/web/20221230225158/https://jeelabs.org/pub/index-c.html) index of weblog posts.
  - RSS Feed (https://web.archive.org/web/20221230225158/https://jeelabs.org/feed/index.html)
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

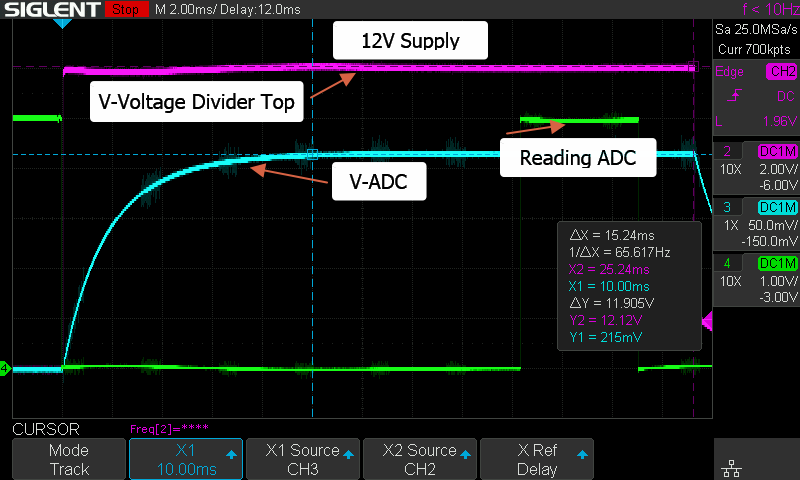
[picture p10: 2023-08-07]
measurements/voltage_divider/voltage_divider_pulse_enable_bss84ak.png

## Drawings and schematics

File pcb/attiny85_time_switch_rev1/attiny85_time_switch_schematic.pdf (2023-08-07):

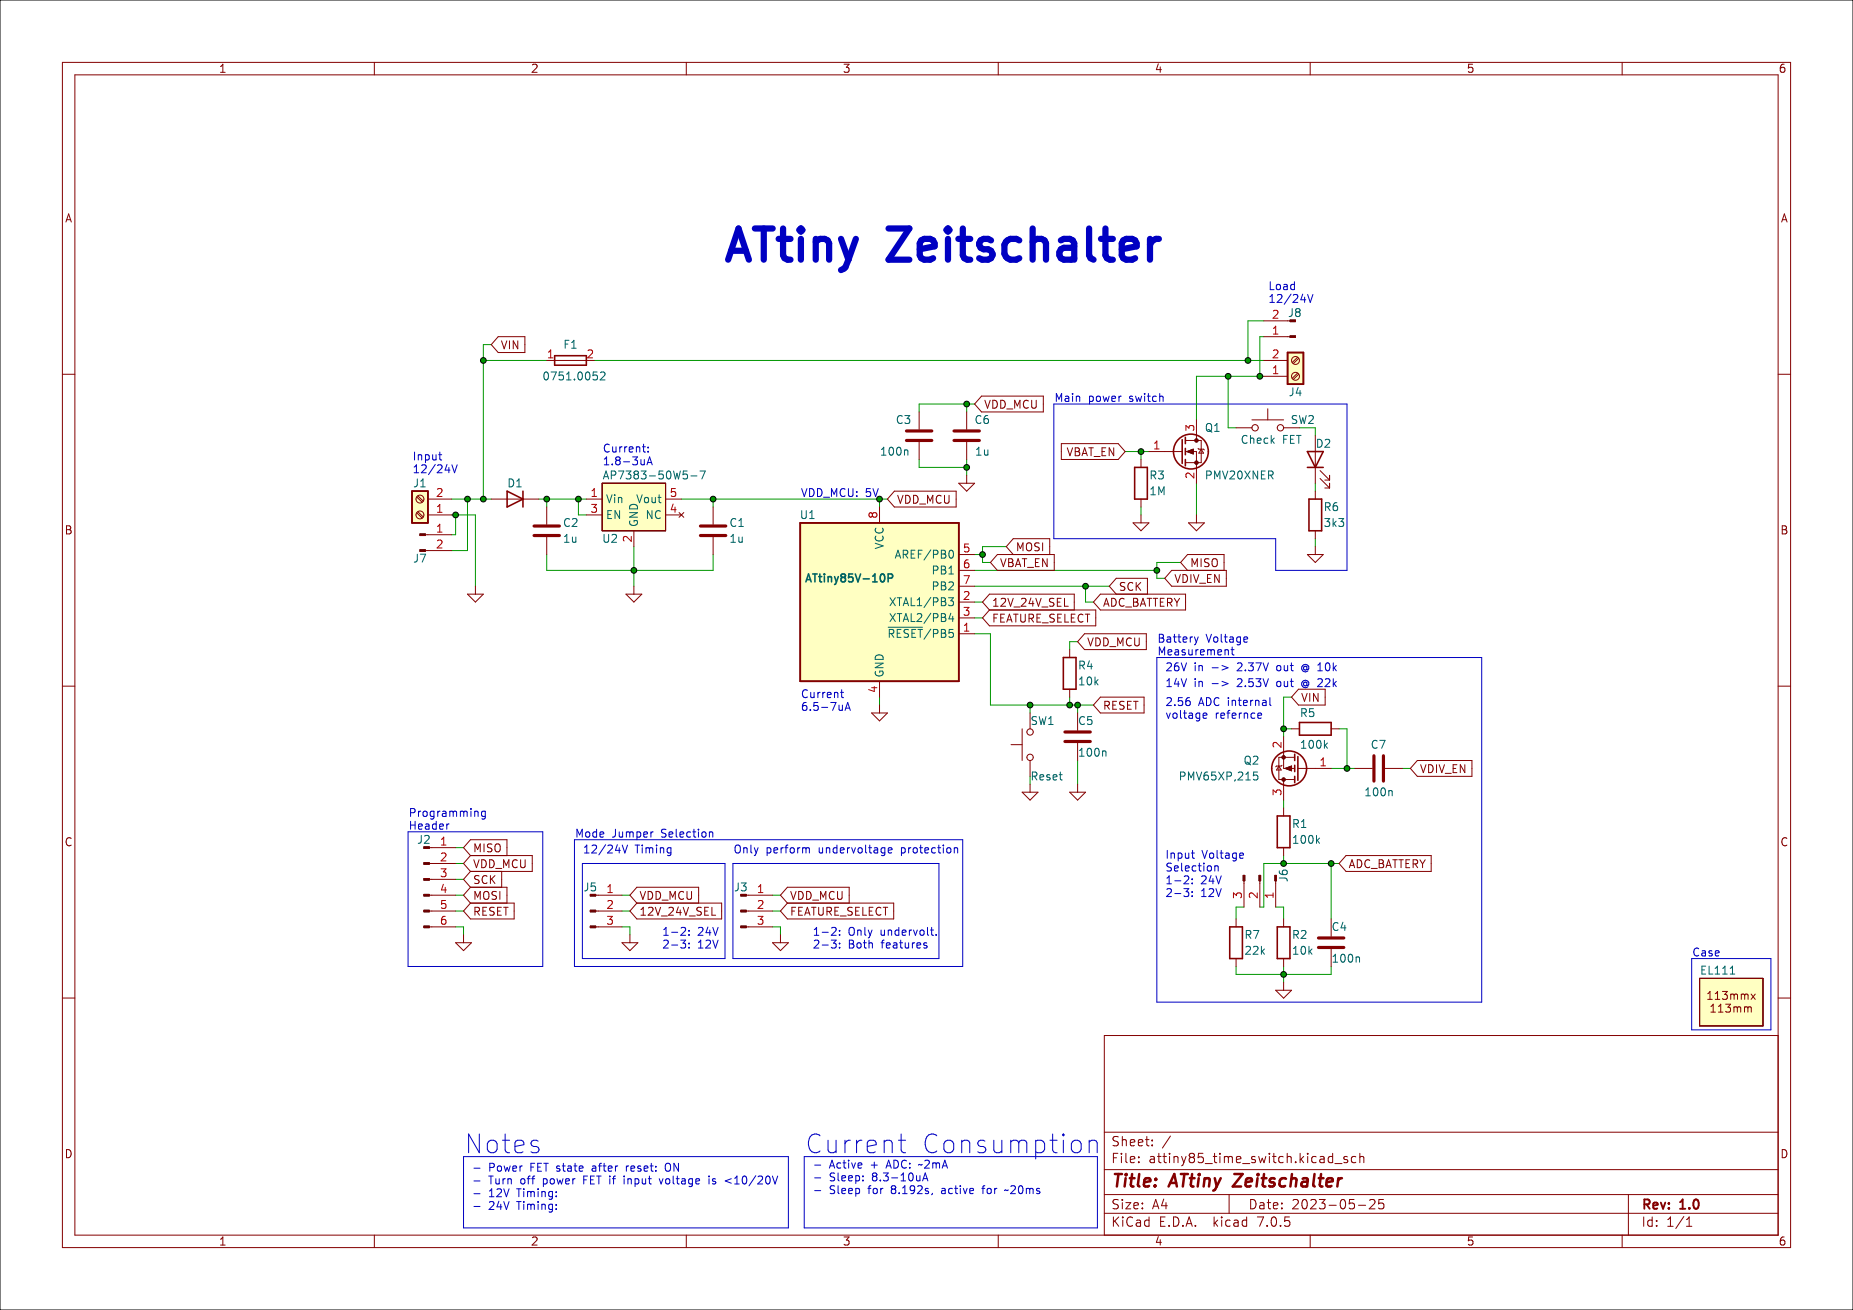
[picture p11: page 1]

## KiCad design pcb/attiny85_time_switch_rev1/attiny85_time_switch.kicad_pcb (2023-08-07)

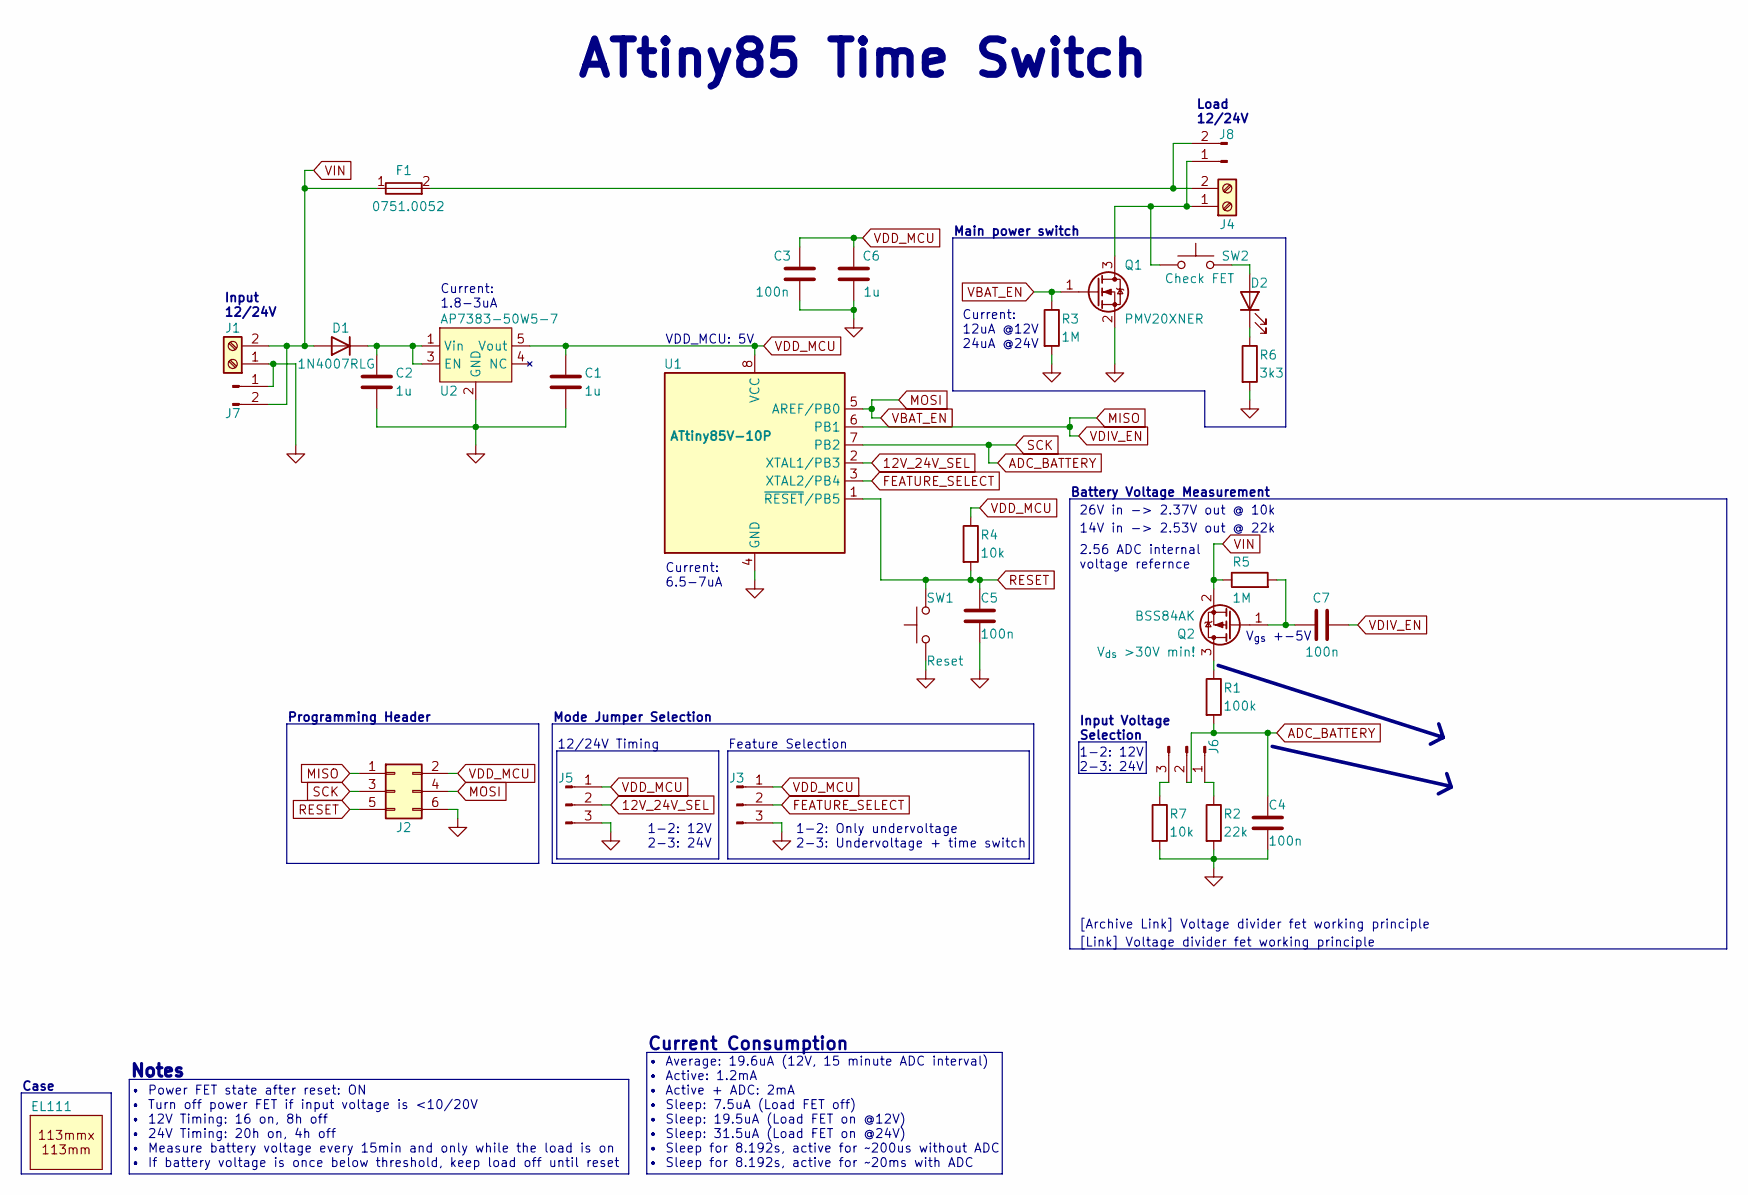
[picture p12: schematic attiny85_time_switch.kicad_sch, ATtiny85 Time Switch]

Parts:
C1, C2, C6: 1u; C_Disc_D3.8mm_W2.6mm_P2.50mm; Manufacturer Part Number FG18X5R1H105KRT06
C3, C4, C5, C7: 100n; C_Disc_D6.0mm_W2.5mm_P5.00mm; Manufacturer Part Number TS170R1H104MSBFB0R
Case1: EL111; Case EL111; Manufacturer Part Number EL111
D1: 1N4007RLG; D_A-405_P7.62mm_Horizontal; MPN 1N4007RLG
D2: LED; LED_D5.0mm; Manufacturer Part Number 703-0100
F1: 0751.0052; 0751.0052_Fuse; Manufacturer Part Number 0751.0052
J1, J4: Screw_Terminal_01x02; TerminalBlock_4Ucon_1x02_P3.50mm_Vertical; Manufacturer Part Number CTB0305/2
J2: Conn_02x03_Odd_Even; PinHeader_2x03_P2.54mm_Vertical; Manufacturer Part Number 2213S-06G
J3, J5, J6: Conn_01x03_Pin; PinHeader_1x03_P2.54mm_Vertical; Manufacturer Part Number SPC20484
J7, J8: Conn_01x02_Pin; PinHeader_1x02_P2.54mm_Vertical; Manufacturer Part Number SPC20484
Q1: PMV20XNER; TSOT-23; Manufacturer Part Number PMV20XNER
Q2: BSS84AK; TSOT-23; Manufacturer Part Number BSS84AK,215
R1: 100k; R_Axial_DIN0204_L3.6mm_D1.6mm_P7.62mm_Horizontal
R2: 22k; R_Axial_DIN0204_L3.6mm_D1.6mm_P7.62mm_Horizontal
R3, R5: 1M; R_Axial_DIN0204_L3.6mm_D1.6mm_P7.62mm_Horizontal
R4, R7: 10k; R_Axial_DIN0204_L3.6mm_D1.6mm_P7.62mm_Horizontal
R6: 3k3; R_Axial_DIN0204_L3.6mm_D1.6mm_P7.62mm_Horizontal
SW1: Reset; SW_PUSH_6mm_H5mm; Manufacturer Part Number TL1105AF160Q
SW2: Check FET; SW_PUSH_6mm_H5mm; Manufacturer Part Number TL1105AF160Q
U1: ATtiny85V-10P; DIP-8_W7.62mm; Manufacturer Part Number ATTINY85V-10PU
U2: AP7383-50W5-7; TSOT-23-5_HandSoldering; Manufacturer Part Number AP7383-50W5-7

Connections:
12V_24V_SEL: J5.2, U1.2 (XTAL1/PB3)
ADC_BATTERY: C4.1, J2.3, J6.2, R1.2, U1.7 (PB2)
FEATURE_SELECT: J3.2, U1.3 (XTAL2/PB4)
GND: C1.2, C2.2, C3.2, C4.2, C5.2, C6.2, J1.1, J2.6, J3.3, J5.3, J7.1, Q1.2, R2.2, R3.2, R6.2, R7.2, SW1.1, U1.4 (GND), U2.2 (GND)
MISO: C7.2, J2.1, U1.6 (PB1)
MOSI: J2.4, Q1.1, R3.1, U1.5 (AREF/PB0)
unnamed: C7.1, Q2.1, R5.2
unnamed: C2.1, D1.1 (K), U2.1 (Vin), U2.3 (EN)
unnamed: D2.2 (A), SW2.2
unnamed: D2.1 (K), R6.1
unnamed: J4.1, J8.1, Q1.3, SW2.1
unnamed: F1.2, J4.2, J8.2
unnamed: J6.1, R2.1
unnamed: J6.3, R7.1
unnamed: Q2.3, R1.1
RESET: C5.1, J2.5, R4.2, SW1.2, U1.1 (~RESET/PB5)
VDD_MCU: C1.1, C3.1, C6.1, J2.2, J3.1, J5.1, R4.1, U1.8 (VCC), U2.5 (Vout)
VIN: D1.2 (A), F1.1, J1.2, J7.2, Q2.2, R5.1

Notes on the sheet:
V_{gs} +-5V
Current: 12uA @12V 24uA @24V
[Archive Link] Voltage divider fet working principle
14V in -> 2.53V out @ 22k
Programming Header
1-2: 12V 2-3: 24V
VDD_MCU: 5V
Notes
Case
Current Consumption
Main power switch
Input Voltage Selection
12/24V Timing
• Power FET state after reset: ON • Turn off power FET if input voltage is <10/20V • 12V Timing: 16 on, 8h off • 24V Timing: 20h on, 4h off • Measure battery voltage every 15min and only while the load is on • If battery voltage is once below threshold, keep load off until reset
[Link] Voltage divider fet working principle
ATtiny85 Time Switch
Current: 6.5-7uA
2.56 ADC internal voltage refernce
Current: 1.8-3uA
Mode Jumper Selection
Battery Voltage Measurement
Load 12/24V
Feature Selection
1-2: 12V 2-3: 24V
26V in -> 2.37V out @ 10k
Input 12/24V
• Average: 19.6uA (12V, 15 minute ADC interval) • Active: 1.2mA • Active + ADC: 2mA • Sleep: 7.5uA (Load FET off) • Sleep: 19.5uA (Load FET on @12V) • Sleep: 31.5uA (Load FET on @24V) • Sleep for 8.192s, active for ~200us without ADC • Sleep for 8.192s, active for ~20ms with ADC
1-2: Only undervoltage 2-3: Undervoltage + time switch

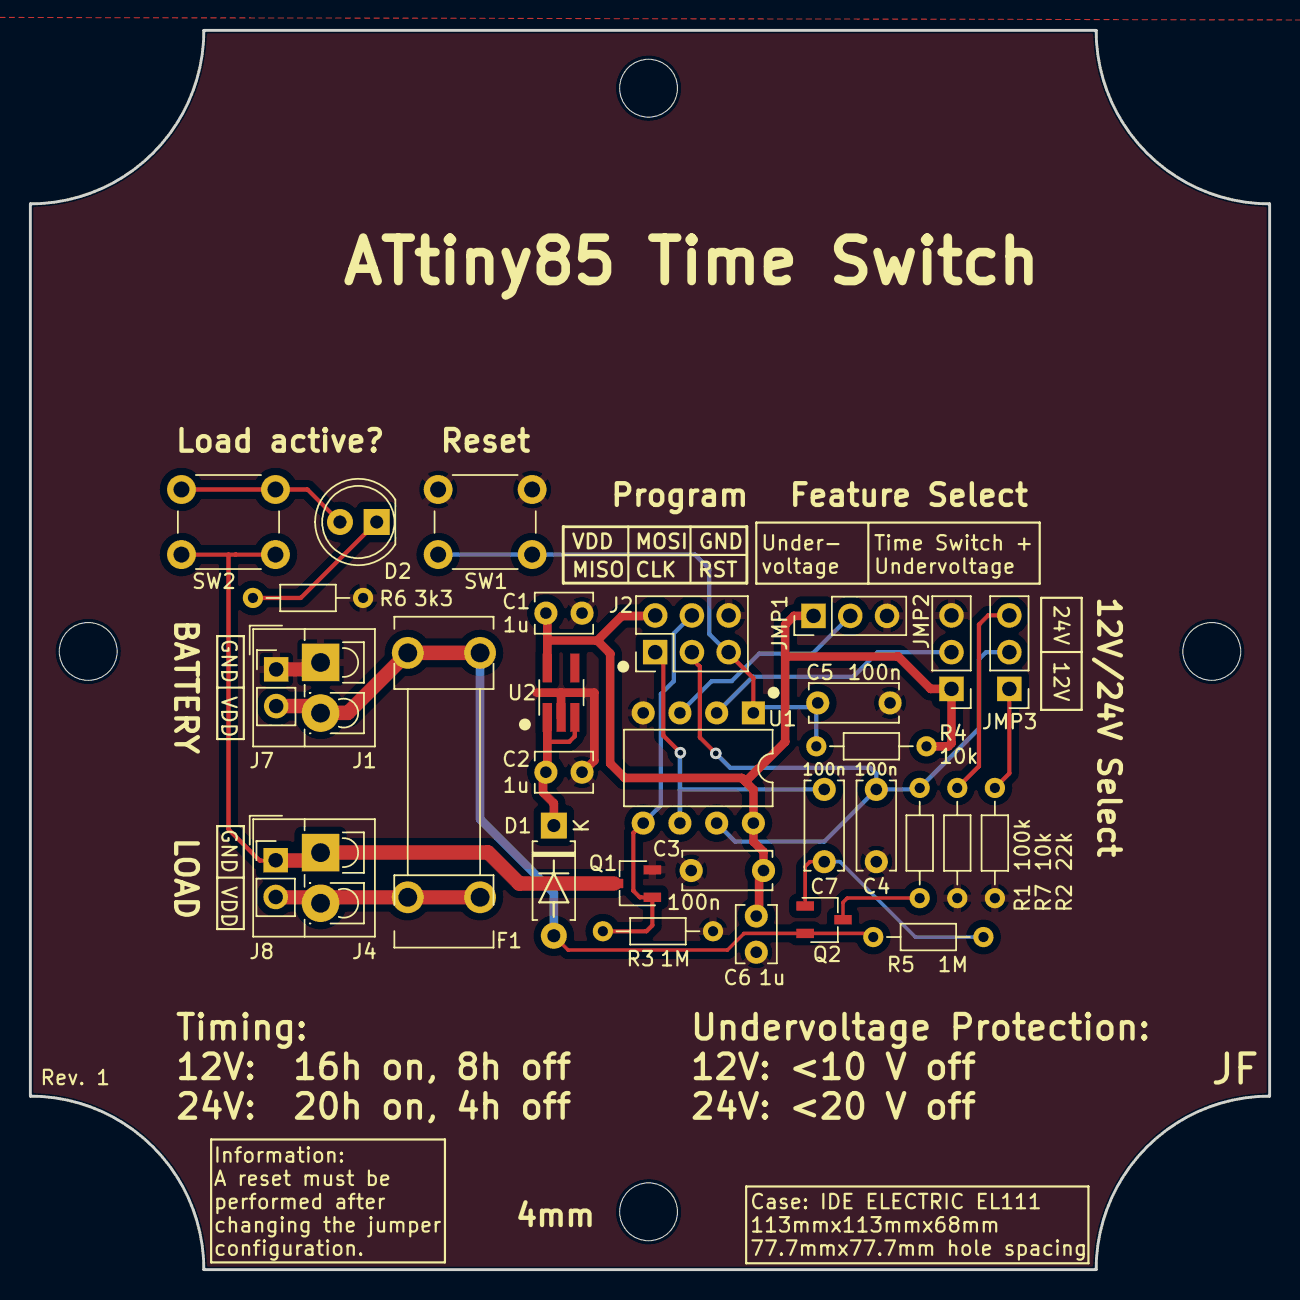
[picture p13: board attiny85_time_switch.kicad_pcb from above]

Board: 2 copper layers, 85.7 x 85.7 mm, 32 parts (0 on the bottom side), 18 nets.

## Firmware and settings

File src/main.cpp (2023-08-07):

/// @file main.cpp
/// ATtiny85:
///   8kB Flash
///   512B RAM
///   512B EEPROM
/// @author JF
/// @date May 10, 2023
/// Unbrick an ATtiny85:
/// https://www.best-microcontroller-projects.com/unbrick-attiny.html
/// https://www.best-microcontroller-projects.com/attiny-ultra-low-power.html
/// Fuses:
/// Regular:
/// L: 0x62: 8MHz divided by 8 -> 1MHz main clock. No clock out.
/// H: 0xD7: EESAVE: EEPROM memory is preserved through the chip erase. SPIEN: enable serial program and data downloading.
/// E: 0xFF: Self-programming disabled.
///
/// Testing
/// L: 0x94: 128kHz. CKOUT: Clock out on PB4 feature select (no jumper!). Requires slow SCK programming clock (max 26kHz).
#include <Arduino.h>
#include <avr/sleep.h>
#include <avr/power.h>
#include <avr/wdt.h>
#include <EEPROM.h>

/// Define relevant pins.
#define VBAT_EN_PIN PB0
#define VDIV_EN_PIN PB1
#define ADC_BATTERY_PIN A1
#define SELECT_12_24V_PIN PB3
#define SELECT_FEATURE_PIN PB4

/// If defined, don't go to sleep but ensure the clock output can be measured on pin PB4 (feature select middle pin).
// #define CLOCK_CALIBRATION_MODE

/// 15min: Battery measurement period. The amount of wakeup cycles corresponding to 15min (8.192s per cycle). 15*60/8.192.
#define TIMING_CYCLES_BATTERY_MEASUREMENT 110u

/// The 10V equivalent raw adc value under which to disable the load for a 12V device (0-1023u).
/// R1: 100k, R2: 22k
/// (Vbat)*(22/122)*(1/2.56V)*1023
/// (10V)*(22/122)*(1/2.56V)*1023
#define ADC_BATTERY_THRESHOLD_12v 721u

/// The 20V equivalent raw adc value under which to disable the load for a 24V device ( 0-1023, (Vbat)*(10/110)*(1/2.56V)*1023).
/// R1: 100k, R2: 10k
/// (Vbat)*(10/110)*(1/2.56V)*1023 )
/// (20V)*(10/110)*(1/2.56V)*1023
#define ADC_BATTERY_THRESHOLD_24v 726u

/// 16h on: 12V. The amount of wakeup cycles corresponding to 8h/28800s for a 12V device (8.192s per cycle). 16*3600/8.192.
#define TIMING_CYCLES_LOAD_ON_12V 7031u
/// 8h off: 12V. The amount of wakeup cycles corresponding to 16h/57600s for a 12V device (8.192s per cycle). 8*3600/8.192.
#define TIMING_CYCLES_LOAD_OFF_12V 3516u

/// 20h on: 24V. The amount of wakeup cycles corresponding to 8h/28800s for a 24V device (8.192s per cycle). 20*3600/8.192.
#define TIMING_CYCLES_LOAD_ON_24V 8789u
/// 4h off: 24V. The amount of wakeup cycles corresponding to 16h/57600s for a 24V device (8.192s per cycle). 4*3600/8.192.
#define TIMING_CYCLES_LOAD_OFF_24V 1758u

/// Possibility to store calibration values in eeprom memory.
enum eeprom_addresses {
    EEPROM_ADDR_CLOCK_CALIB_3_MSB = 0x0u,
    EEPROM_ADDR_CLOCK_CALIB_2,
    EEPROM_ADDR_CLOCK_CALIB_1,
    EEPROM_ADDR_CLOCK_CALIB_0_LSB,
    EEPROM_ADDR_CLOCK_CALIB_MAGIC_NUMBER
};

// The magic number that must be present in the eeprom to apply the clock calibration algorithm.
#define EEPROM_CLOCK_CALIB_MAGIC_NUMBER 0xCDu

/// The value of the 128kHz clock used to clock the sleep watchdog timer.
#define SLEEP_CLOCK_VALUE_HZ 128000lu

/// The maximum deviation from @ref SLEEP_CLOCK_VALUE_HZ above or below which to discard clock calibration values.
#define SLEEP_CLOCK_DEVIATION_MAX_HZ 30000lu

/// The clock calibration gets read from eeprom at startup.
static uint32_t clock_calibration;

/// All features active or only the undervoltage protection is active. Selectable by a jumper.
static bool all_features_activated;

/// The timing for the load on/off feature with the selectable 12/24V jumper.
static uint16_t timing_cycles_load_on;
static uint16_t timing_cycles_load_off;

/// The raw adc threshold under which to disable the load.
static uint16_t undervoltage_adc_threshold;

/// Turn on the watchdog to wake the system from sleep.
/// The timeout value is 1048576 cycles @128kHz (8.192s).
static void enable_watchdog(void);

/// Enable the low power sleep mode.
static void go_to_sleep(void);

/// Initialize all used gpios with their respective driver level.
static void initialize_gpios(void);

/// Enable/disable the adc peripheral. Must be disabled before entering
/// sleep to save ~300uA. Uses the 2.56 V internal reference.
///
/// @param enable True to enable the adc.
static void enable_adc(bool enable);

/// Enable/disable the voltage divider for measuring the battery voltage.
///
/// @param enable True to enable the voltage divider, false to disable it.
static void enable_voltage_divider(bool enable);

/// Enable/disable the n-fet load switch.
///
/// @param enable True to enable the load, false to disable it.
static void enable_load(bool enable);

/// Check if the load is currently activatedd.
///
/// @return True if the load is activated.
static bool is_load_enabled(void);

/// Get the currently selected 12V/24V timing mode.
///
/// @return True: 12V timing, false: 24V timing.
static bool get_12V_24V_selection(void);

/// Get the currently selected feature mode.
///
/// @return True: all features, false: only undervoltage protection.
static bool get_feature_selection(void);

/// Check if the feature to enable/disable the load in regular intervals is currently active.
///
/// @return True if the load timing is active.
static bool load_timing_activated(void);

/// Read the current battery voltage.
///
/// @return The battery voltage as a 10 bit value.
static uint16_t read_battery_voltage(void);

/// Read the pre-programmed clock calibration value.
///
/// @return The clock calibration value.
static uint32_t read_clock_calibration(void);

/// Apply the clock calibration calculation to obtain a more precise sleep timing behaviour.
///
/// @param clock_calibration The clock calibration read from the eeprom.
/// @param uncalibrated_value The uncalibrated value.
/// @return The calibrated value.
static uint32_t apply_clock_calibration(uint32_t clock_calibration, uint32_t uncalibrated_value);

/// Checks whether the @ref EEPROM_CLOCK_CALIB_MAGIC_NUMBER is present in the eeprom.
/// If yes, the clock calibration algorithm will be run.
///
/// @return True if the clock calibration values are present.
static bool clock_calibration_present(void);

static void enable_voltage_divider(bool enable) {
    digitalWrite(VDIV_EN_PIN, enable ? LOW : HIGH);
}

static void enable_load(bool enable) {
    digitalWrite(VBAT_EN_PIN, enable ? HIGH : LOW);
}

static bool is_load_enabled(void) {
    return digitalRead(VBAT_EN_PIN) == HIGH;
}

static bool get_12V_24V_selection(void) {
    return digitalRead(SELECT_12_24V_PIN) == HIGH;
}

static bool get_feature_selection(void) {
    return digitalRead(SELECT_FEATURE_PIN) == LOW;
}

static bool load_timing_activated(void) {
    return all_features_activated == true;
}

static void enable_adc(bool enable) {
    if (enable) {
        bitSet(ADCSRA, ADEN);
        analogReference(INTERNAL2V56_NO_CAP);
    } else {
        bitClear(ADCSRA, ADEN);
    }
}

static uint16_t read_battery_voltage(void) {
    // The amount of averages to take from the adc reading. Must be a power of two.
#define ADC_AVERAGE_NUM 32u
#define ADC_DIVISION_SHIFT 5u // 2^ADC_DIVISION_SHIFT = ADC_AVERAGE_NUM
    uint16_t battery_voltage = 0u;

    // Enable the adc.
    enable_adc(true);

    // Quickly pulse the gate of the p-fet of the voltage divider to enable it.
    // Now the voltage divider is active for 230ms.
    enable_voltage_divider(true);

    // Wait 18ms to let all voltages stabilize.
    delay(18);

    // Read the ADC value (32*1023 = 32736 as a max value, fits in 16-bits).
    for (uint8_t adc_reading = 0u; adc_reading < ADC_AVERAGE_NUM; adc_reading++) {
        battery_voltage += analogRead(ADC_BATTERY_PIN);
    }

    // Divide the accumulated readings.
    battery_voltage = battery_voltage >> ADC_DIVISION_SHIFT;

    // Wait 2ms and turn off the voltage divider.
    delay(2);
    enable_voltage_divider(false);

    // Finally turn off the adc.
    enable_adc(false);

    return battery_voltage;
}

ISR(WDT_vect) {
    wdt_disable();
}

static void enable_watchdog(void) {
    //  MCU Status Register, clear reset cause (pg. 45).
    MCUSR = 0;

    // Watchdog Timer Control Register (pg. 45)
    // WDE:  Watchdog enable.
    // WDIF: Watchdog timeout interrupt flag.
    // WDCE: Watchdog change enable
    WDTCR = bit(WDCE) | bit(WDE) | bit(WDIF);

    // set WDIE ( Interrupt only, no Reset )
    // WDIE: Watchdog timeout interrupt enable.
    // WDP:  Prescaler: 1048576 cycles @32.768kHz: 32s | bit(WDP3) | bit(WDP0)
    WDTCR = bit(WDIE) | bit(WDP3) | bit(WDP0); // 8.192s
    // WDTCR = bit(WDIE) | bit(WDP2) | bit(WDP1) | bit(WDP0); // 2s.
    // WDTCR = bit(WDIE) | bit(WDP1) | bit(WDP0); // 125ms.

    // Finally reset the watchdog.
    wdt_reset();
}

static void go_to_sleep(void) {
    // Set the correct sleep mode.
    set_sleep_mode(SLEEP_MODE_PWR_DOWN);

    cli();
    enable_watchdog();
    sleep_enable();
    sei();

    // Go to sleep.
    sleep_cpu();

    // Clear the SE (Sleep Enable) bit of the MCUCR ( MCU Control Register) immediately after wakeup.
    sleep_disable();
}

static void initialize_gpios(void) {
    // The fet for enabling/disabling the voltage divider.
    pinMode(VDIV_EN_PIN, OUTPUT);
    enable_voltage_divider(false);

    // The fet for enabling/disabling the load.
    pinMode(VBAT_EN_PIN, OUTPUT);
    enable_load(false);

    // The feature selection jumpers.
    pinMode(SELECT_12_24V_PIN, INPUT);
    pinMode(SELECT_FEATURE_PIN, INPUT);
}

static uint32_t read_clock_calibration(void) {
    uint32_t clock_calib;
    clock_calib = ((uint32_t)EEPROM.read(EEPROM_ADDR_CLOCK_CALIB_3_MSB) << 24u) |
                  ((uint32_t)EEPROM.read(EEPROM_ADDR_CLOCK_CALIB_2) << 16u) |
                  ((uint32_t)EEPROM.read(EEPROM_ADDR_CLOCK_CALIB_1) << 8u) |
                  (uint32_t)EEPROM.read(EEPROM_ADDR_CLOCK_CALIB_0_LSB);
    return (clock_calib == 0xFFFFFFFFlu) ? 0u : clock_calib;
}

static uint32_t apply_clock_calibration(uint32_t clock_calibration, uint32_t uncalibrated_value) {
    // Discard too high or too low calibration values.
    if ((clock_calibration < (SLEEP_CLOCK_VALUE_HZ - SLEEP_CLOCK_DEVIATION_MAX_HZ)) ||
        clock_calibration > (SLEEP_CLOCK_VALUE_HZ + SLEEP_CLOCK_DEVIATION_MAX_HZ)) {
        return uncalibrated_value;
    }

    return (clock_calibration * uncalibrated_value) / SLEEP_CLOCK_VALUE_HZ;
}

static bool clock_calibration_present(void) {
    return (EEPROM.read(EEPROM_ADDR_CLOCK_CALIB_MAGIC_NUMBER) == EEPROM_CLOCK_CALIB_MAGIC_NUMBER);
}

void setup() {
    // Set all gpios to their default level.
    initialize_gpios();

    // Only enable the adc if a battery voltage measurement is ongoing.
    enable_adc(false);

    // Read in the pre-programmed clock calibration value.
    clock_calibration = read_clock_calibration();

    // Read the feature selection jumper.
    all_features_activated = get_feature_selection();

    // Read the 12/24V selection jumper.
    bool _12_24V_selection = get_12V_24V_selection();

    // Apply the correct timing.
    timing_cycles_load_on = (_12_24V_selection == true) ? TIMING_CYCLES_LOAD_ON_12V : TIMING_CYCLES_LOAD_ON_24V;
    timing_cycles_load_off = (_12_24V_selection == true) ? TIMING_CYCLES_LOAD_OFF_12V : TIMING_CYCLES_LOAD_OFF_24V;
    undervoltage_adc_threshold = (_12_24V_selection == true) ? ADC_BATTERY_THRESHOLD_12v : ADC_BATTERY_THRESHOLD_24v;

    // Check whether to apply a clock calibration, if yes adjust the timing values accordingly.
    if (clock_calibration_present()) {
        timing_cycles_load_on = apply_clock_calibration(clock_calibration, timing_cycles_load_on);
        timing_cycles_load_off = apply_clock_calibration(clock_calibration, timing_cycles_load_off);
    }

    // Start with the load on.
    enable_load(true);
}

void loop() {
    static uint16_t wakeup_count_load_feature = 0u;
    static uint16_t wakeup_count_undervoltage_protection = 0u;
    static bool undervoltage_protection_triggered = false;
    typedef enum wake_states {
        STATE_LOAD_ON,
        STATE_LOAD_OFF,
    } wake_states_t;
    static wake_states_t wake_state = STATE_LOAD_ON;

    // Loop forever if clock calibration mode is selected.
#ifdef CLOCK_CALIBRATION_MODE
    while (true) {
    }
#endif

    go_to_sleep();
    wakeup_count_load_feature++;
    wakeup_count_undervoltage_protection++;

    // Periodically measure the battery voltage if the load is active.
    if (is_load_enabled() && (wakeup_count_undervoltage_protection >= TIMING_CYCLES_BATTERY_MEASUREMENT)) {
        wakeup_count_undervoltage_protection = 0u;

        // Disable the load if the battery voltage falls under the predefined threshold.
        if (read_battery_voltage() < undervoltage_adc_threshold) {
            enable_load(false);
            undervoltage_protection_triggered = true;
        }
    }

    // If the feature selection jumper is set to all features, enable/disable the load regularly.
    // If the battery voltage has once fallen under the threshold, never activate the load again.
    if (load_timing_activated() && !undervoltage_protection_triggered) {
        switch (wake_state) {
        case STATE_LOAD_ON: {
            if (wakeup_count_load_feature >= timing_cycles_load_on) {
                wakeup_count_load_feature = 0u;
                enable_load(false);
                wake_state = STATE_LOAD_OFF;
            }
            break;
        }

        case STATE_LOAD_OFF: {
            if (wakeup_count_load_feature >= timing_cycles_load_off) {
                wakeup_count_load_feature = 0u;
                enable_load(true);
                wake_state = STATE_LOAD_ON;
            }
            break;
        }

        default: {
            wake_state = STATE_LOAD_OFF;
            break;
        }
        }
    }
}

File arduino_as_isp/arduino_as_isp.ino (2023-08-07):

// ArduinoISP
// Copyright (c) 2008-2011 Randall Bohn
// If you require a license, see
// https://opensource.org/licenses/bsd-license.php
//
// This sketch turns the Arduino into a AVRISP using the following Arduino pins:
//
// Pin 10 is used to reset the target microcontroller.
//
// By default, the hardware SPI pins MISO, MOSI and SCK are used to communicate
// with the target. On all Arduinos, these pins can be found
// on the ICSP/SPI header:
//
//               MISO °. . 5V (!) Avoid this pin on Due, Zero...
//               SCK   . . MOSI
//                     . . GND
//
// On some Arduinos (Uno,...), pins MOSI, MISO and SCK are the same pins as
// digital pin 11, 12 and 13, respectively. That is why many tutorials instruct
// you to hook up the target to these pins. If you find this wiring more
// practical, have a define USE_OLD_STYLE_WIRING. This will work even when not
// using an Uno. (On an Uno this is not needed).
//
// Alternatively you can use any other digital pin by configuring
// software ('BitBanged') SPI and having appropriate defines for PIN_MOSI,
// PIN_MISO and PIN_SCK.
//
// IMPORTANT: When using an Arduino that is not 5V tolerant (Due, Zero, ...) as
// the programmer, make sure to not expose any of the programmer's pins to 5V.
// A simple way to accomplish this is to power the complete system (programmer
// and target) at 3V3.
//
// Put an LED (with resistor) on the following pins:
// 9: Heartbeat   - shows the programmer is running
// 8: Error       - Lights up if something goes wrong (use red if that makes sense)
// 7: Programming - In communication with the target
//

#include "Arduino.h"
#undef SERIAL

// Configure SPI clock (in Hz).
// E.g. for an ATtiny @ 128 kHz: the datasheet states that both the high and low
// SPI clock pulse must be > 2 CPU cycles, so take 3 cycles i.e. divide target
// f_cpu by 6:
//     #define SPI_CLOCK            (128000/6)
//
// A clock slow enough for an ATtiny85 @ 1 MHz, is a reasonable default:

// For normal clock.
// #define SPI_CLOCK (1000000 / 6)

// For slow clock (128kHz).
#define SPI_CLOCK (25000 / 6)

#define PROG_FLICKER true

// Select hardware or software SPI, depending on SPI clock.
// Currently only for AVR, for other architectures (Due, Zero,...), hardware SPI
// is probably too fast anyway.

#if defined(ARDUINO_ARCH_AVR)

#if SPI_CLOCK > (F_CPU / 128)
#define USE_HARDWARE_SPI
#endif

#endif

// Configure which pins to use:

// The standard pin configuration.
#ifndef ARDUINO_HOODLOADER2

#define RESET 10  // Use pin 10 to reset the target rather than SS
#define LED_HB 9
#define LED_ERR 8
#define LED_PMODE 7

// Uncomment following line to use the old Uno style wiring
// (using pin 11, 12 and 13 instead of the SPI header) on Leonardo, Due...

// #define USE_OLD_STYLE_WIRING

#ifdef USE_OLD_STYLE_WIRING

#define PIN_MOSI 11
#define PIN_MISO 12
#define PIN_SCK 13

#endif

// HOODLOADER2 means running sketches on the ATmega16U2 serial converter chips
// on Uno or Mega boards. We must use pins that are broken out:
#else

#define RESET 4
#define LED_HB 7
#define LED_ERR 6
#define LED_PMODE 5

#endif

// By default, use hardware SPI pins:
#ifndef PIN_MOSI
#define PIN_MOSI MOSI
#endif

#ifndef PIN_MISO
#define PIN_MISO MISO
#endif

#ifndef PIN_SCK
#define PIN_SCK SCK
#endif

// Force bitbanged SPI if not using the hardware SPI pins:
#if (PIN_MISO != MISO) || (PIN_MOSI != MOSI) || (PIN_SCK != SCK)
#undef USE_HARDWARE_SPI
#endif


// Configure the serial port to use.
//
// Prefer the USB virtual serial port (aka. native USB port), if the Arduino has one:
//   - it does not autoreset (except for the magic baud rate of 1200).
//   - it is more reliable because of USB handshaking.
//
// Leonardo and similar have an USB virtual serial port: 'Serial'.
// Due and Zero have an USB virtual serial port: 'SerialUSB'.
//
// On the Due and Zero, 'Serial' can be used too, provided you disable autoreset.
// To use 'Serial': #define SERIAL Serial

#ifdef SERIAL_PORT_USBVIRTUAL
#define SERIAL SERIAL_PORT_USBVIRTUAL
#else
#define SERIAL Serial
#endif


// Configure the baud rate:

#define BAUDRATE 19200
// #define BAUDRATE	115200
// #define BAUDRATE	1000000


#define HWVER 2
#define SWMAJ 1
#define SWMIN 18

// STK Definitions
#define STK_OK 0x10
#define STK_FAILED 0x11
#define STK_UNKNOWN 0x12
#define STK_INSYNC 0x14
#define STK_NOSYNC 0x15
#define CRC_EOP 0x20  //ok it is a space...

void pulse(int pin, int times);

#ifdef USE_HARDWARE_SPI
#include "SPI.h"
#else

#define SPI_MODE0 0x00

#if !defined(ARDUINO_API_VERSION) || ARDUINO_API_VERSION != 10001  // A SPISettings class is declared by ArduinoCore-API 1.0.1
class SPISettings {
public:
  // clock is in Hz
  SPISettings(uint32_t clock, uint8_t bitOrder, uint8_t dataMode)
    : clockFreq(clock) {
    (void)bitOrder;
    (void)dataMode;
  };

  uint32_t getClockFreq() const {
    return clockFreq;
  }

private:
  uint32_t clockFreq;
};
#endif                                                             // !defined(ARDUINO_API_VERSION)

class BitBangedSPI {
public:
  void begin() {
    digitalWrite(PIN_SCK, LOW);
    digitalWrite(PIN_MOSI, LOW);
    pinMode(PIN_SCK, OUTPUT);
    pinMode(PIN_MOSI, OUTPUT);
    pinMode(PIN_MISO, INPUT);
  }

  void beginTransaction(SPISettings settings) {
    pulseWidth = (500000 + settings.getClockFreq() - 1) / settings.getClockFreq();
    if (pulseWidth == 0) {
      pulseWidth = 1;
    }
  }

  void end() {}

  uint8_t transfer(uint8_t b) {
    for (unsigned int i = 0; i < 8; ++i) {
      digitalWrite(PIN_MOSI, (b & 0x80) ? HIGH : LOW);
      digitalWrite(PIN_SCK, HIGH);
      delayMicroseconds(pulseWidth);
      b = (b << 1) | digitalRead(PIN_MISO);
      digitalWrite(PIN_SCK, LOW);  // slow pulse
      delayMicroseconds(pulseWidth);
    }
    return b;
  }

private:
  unsigned long pulseWidth;  // in microseconds
};

static BitBangedSPI SPI;

#endif

void setup() {
  SERIAL.begin(BAUDRATE);

  pinMode(LED_PMODE, OUTPUT);
  pulse(LED_PMODE, 2);
  pinMode(LED_ERR, OUTPUT);
  pulse(LED_ERR, 2);
  pinMode(LED_HB, OUTPUT);
  pulse(LED_HB, 2);
}

int ISPError = 0;
int pmode = 0;
// address for reading and writing, set by 'U' command
unsigned int here;
uint8_t buff[256];  // global block storage

#define beget16(addr) (*addr * 256 + *(addr + 1))
typedef struct param {
  uint8_t devicecode;
  uint8_t revision;
  uint8_t progtype;
  uint8_t parmode;
  uint8_t polling;
  uint8_t selftimed;
  uint8_t lockbytes;
  uint8_t fusebytes;
  uint8_t flashpoll;
  uint16_t eeprompoll;
  uint16_t pagesize;
  uint16_t eepromsize;
  uint32_t flashsize;
} parameter;

parameter param;
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

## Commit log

2023-08-07 🎉 Initial commit.
    [attiny85_time_switch-B_Cu.gbr, attiny85_time_switch-B_Mask.gbr, attiny85_time_switch-B_Paste.gbr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]
2023-08-07 📝 Updated readme.
2024-01-11 📝 Updated documentation on the zero power measurement link.
    [attiny85_time_switch.kicad_sch]
2024-02-07 📝 Updated documentation.
2024-02-07 🚚 Renamed pcb project with revision.
    [attiny85_time_switch-B_Cu.gbr, attiny85_time_switch-B_Mask.gbr, attiny85_time_switch-B_Paste.gbr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]
2024-02-07 🧱 More renamin.
    [attiny85_time_switch-B_Cu.gbr, attiny85_time_switch-B_Mask.gbr, attiny85_time_switch-B_Paste.gbr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]

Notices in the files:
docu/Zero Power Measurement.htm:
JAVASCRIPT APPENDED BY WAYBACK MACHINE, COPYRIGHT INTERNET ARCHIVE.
